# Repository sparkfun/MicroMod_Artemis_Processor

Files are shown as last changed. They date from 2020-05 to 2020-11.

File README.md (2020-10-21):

SparkFun MicroMod Artemis Processor Board
========================================

SparkFun MicroMod Artemis Processor Board

[*SparkFun MicroMod Artemis Processor Board (16401)*](https://www.sparkfun.com/products/16401)

Leveraging the ultra powerful Artemis Module, the SparkFun MicroMod Artemis Processor is the brain board of your dreams. Need Machine Learning capabilities? We gotcha. Need Bluetooth? We gotcha. Need I<sup>2</sup>C functionality to connect to all our amazing Qwiic boards? We totally gotcha.  

At the heart of SparkFun's Artemis module is Ambiq Micro's Apollo3 processor, whose ultra-efficient ARM Cortex-M4F processor is spec’d to run TensorFlow Lite using only 6uA/MHz. We've routed 2 I<sup>2</sup>C buses, 8 GPIO, dedicated digital, analog, and PWM pins, multiple SPI as well as QuadSPI, and Bluetooth to boot. You really can't go wrong with this processor. Grab one today, pick up a compatible carrier board, and get hacking! 

Repository Contents
-------------------

* **/Hardware** - Eagle design files (.brd, .sch)
* **/TestSketches** - Related software for the MicroMod Artemis Processor Board

Documentation
--------------
* **[Hookup Guide](https://learn.sparkfun.com/tutorials/micromod-artemis-processor-board-hookup-guide)** - Basic hookup guide for the MicroMod Artemis Processor Board.
* **[Getting Started with MicroMod](https://learn.sparkfun.com/tutorials/getting-started-with-micromod)** - A tutorial to help you get started with the MicroMod Ecosystem. 
* **[Designing with MicroMod](https://learn.sparkfun.com/tutorials/designing-with-micromod)** - A tutorial to walk you through the specs of the MicroMod processor and carrier board as well as the basics of incorporating the MicroMod form factor into your own PCB designs.

License Information
-------------------

This product is _**open source**_! 

Please review the LICENSE.md file for license information. 

If you have any questions or concerns on licensing, please contact technical support on our [SparkFun forums](https://forum.sparkfun.com/viewforum.php?f=152).

Distributed as-is; no warranty is given.

- Your friends at SparkFun.

_<COLLABORATION CREDIT>_

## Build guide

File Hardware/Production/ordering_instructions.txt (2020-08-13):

panel size, 194x70mm
PCB thickness, 0.8mm
number of layers, 4
soldermask color, Red
silkscreen color, White
oz copper, 1oz
finish, HASL lead free
stencils, none
pcs per panel, 16
min trace width, 0.1016mm / 0.0040in
min drill size, 0.2000mm / 0.0079in
filename to layer stackup 1/2/3/4: GTL, GL2, GL3, GBL

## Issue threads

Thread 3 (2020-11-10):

Battery voltage calculations with loaded voltage divider

adamgarbo, 2020-11-10:
Hi there,

I've been attempting to calculate the battery voltage using the Artemis Process and MicroMod Data Logging Carrier Board (MMDLCB).

From the schematics, we can observe that the 20 kΩ/10 kΩ voltage divider from the MMDLCB is loading the 100 kΩ/150 kΩ voltage divider on the Artemis. The circuit simplifies down to the following:

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

I've done the math to calculate the voltage across VR4, which seems to checkout, but the problem is the same calculations using the analog readings I'm getting on the Artemis don't appear to add up. I wrote the following code to test:

```
const float R1 = 20000.0;
const float R2 = 10000.0;
const float R3 = 100000.0;
const float R4 = 150000.0;
float R234 = 1.0 / ((1.0 / R2) + (1.0 / (R3 + R4)));

void setup() {

  Serial.begin(115200);
  while (!Serial);
  analogReadResolution(14);

  Serial.printf("R1: %.2f\n", R1);
  Serial.printf("R2: %.2f\n", R2);
  Serial.printf("R3: %.2f\n", R3);
  Serial.printf("R4: %.2f\n", R4);
  Serial.printf("R234: %.2f\n", R234);
}

void loop() {

  int VR4_ANALOG = analogRead(BATTVIN3);
  float VR4 = float(VR4_ANALOG) * 2.0 / 16384.0;
  float VR2 = VR4 * (R3 + R4) / R4;
  float VIN = VR2 * (R234 + R1) / R234;
  Serial.printf("VR4_ANALOG: %d VR4: %.2f VR2: %.2f VS: %.2f \n", VR4_ANALOG, VR4, VR2, VIN);
  delay(1000);
}
```

I'm wondering if perhaps I'm missing something regarding which ADC voltages are used. I've been operating under the assumption that the 2.0 V reference should be used.

Would be great to get some clarification on this (or for someone to double-check my math).

Cheers,
Adam

adamgarbo, 2020-11-10:
@PaulZC reminded me that we've encountered this issue before!

https://github.com/sparkfun/OpenLog_Artemis/issues/11#issuecomment-637340564

By the sounds of it, the higher resistance is worsening our accuracy and a correction factor will be needed to calculate the correct battery voltage measurement.

PaulZC, 2020-12-10:
Hi Adam (@adamgarbo ),
You've correctly spotted that the second divider will be loading the first and throwing the measurement off, but yes the 100k divider will limit how fast the ADC sample-and-hold capacitor can charge up leading to further scale errors.
In this case, I think you need a hybrid model that takes both effects into account.
All the best,
Paul

nseidle, 2020-12-10:
As I have learned recently with the [RTK Surveyor](https://www.sparkfun.com/products/17369), you may be better off with a fuel gauge IC such as the MAX1704x family (MAX17048 is what we use). These very low power devices are much better at correctly measuring a battery in a low-power situation.

adamgarbo, 2021-03-19:
Hi @PaulZC,

I'm revisiting this issue as I have a number of projects based on the Artemis Processor on the go and am hoping to find a way to make use of the Artemis' onboard battery voltage divider.

I read over your GitHub issue investigating using a voltage divider with the OpenLog Artemis. Would you be able to offer any insight on how to calculate a correction factor to use with the voltage dividers on the Artemis Processor and Data Logging Carrier Board? Will it be a matter of applying known voltages to the circuit and calculating backwards to properly scale the readings? This has really been making my brain hurt!

@nseidle is the plan to do away with the voltage divider entirely on the next hardware revision of the Artemis Processor?

Cheers,
Adam

PaulZC, 2021-03-19:
Hi @adamgarbo ,
Here's what I would do:
Apply a known, measured voltage. Step the voltage up in say 0.1V increments. Record the raw ADC codes from the analogRead. Throw the results into a spreadsheet and fit a y = ax + b line to them. You need to find the gain term (a) and there is probably an offset too (b) which may be negative.
I had to do the same thing on an ESP32 project recently.
It's a bit more tricky if you're calibrating the battery voltage circuit as you are then limited to say 3.6V up to whatever the maximum the voltage regulator can handle is. Usually around 6.0V. But it works.
Everything should be linear, you shouldn't have to introduce an x^2 term.
Cheers,
Paul

PaulZC, 2021-03-19:
Here's the spreadsheet from the ESP32 project.
Column A is the 'battery' voltage from a lab power supply.
Column C is the raw ADC reading.
The graph is raw ADC vs. voltage. It's linear.
Cell B6 is the voltage range (max - min).
Cell D6 is the ADC range (max - min).
Cell D8 is the calculated gain term: ADC range / voltage range.
Cell E8 is the offset term, entered manually and tweaked up and down until the values is column F look right - when compared to column C.
Column E is battery voltage minus offset.
Column F is (battery voltage - offset) * gain term.
Column H is the predicted voltages from the equation (ADC / CellD8) + CellE8 which, as I check, I compare visually to column A.
So, in this case, battery voltage = (raw ADC / 392) + 0.565.
Enjoy!

[ESP32_VIN.zip](https://github.com/sparkfun/MicroMod_Artemis_Processor/files/6169684/ESP32_VIN.zip)

adamgarbo, 2021-03-19:
Thanks, Paul!

It sounds like it's time to go dig up a power supply from the lab.

Am I correct in assuming the op-amp issues with the Artemis Processor shouldn't be a problem when characterizing the voltage measurements, since BATTVIN3 will only see at most 6.0 V / 3 = 2.0 V, which is within the limited 2.9 V range?

I see now why Nathan recommends the MAX17048 IC fuel gauge!

Cheers,
Adam

idea--list, 2021-10-10:
@adamgarbo
I think the best option to power Apollo3 chips is to use LiFePO batteries as the highest voltage this chip can tolerate is 3.63V.
LiFePOs are suit better for ultra low power applications than LiPOs, can tolerate cold wheather much better, have much longer lifecycles and cost way less per Wh, though their energy density is lower.
Now all the Sparkfun boards can be operated with LiPO batteries only as the SFE boards include power regulators that suit LiPOs and output constant 3V3 ...but exactly that is why reading the voltage divider built into the Apollo3 chips does not make any sense on SFE boards.

Instead i rely on a 2M and a 1M external resistor to have _**rough**_ estimate readings for LiPOs... as the voltage of LiFePOs hardly changes, dividers do not make much sense with that type of batteries.

IMHO the best option is what Nathan suggested.

adamgarbo, 2022-10-23:
Issue closed as unresolved.

Closed 2022-10-23.

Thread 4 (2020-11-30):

Incorrect analogRead() measurements

adamgarbo, 2020-11-30:
Howdy,

There currently appears to be an issue with obtaining correct analogRead() measurements with the Artemis Processor.

Plugging into the MicroMod Data Logging Carrier Board and running the Artemis example: `Example4_analogRead` reveals that when tied to GND, the analog measurement is correct (0). However, when 3.3 V is applied, the analog reading maxes out at ~15890/16384.

```
10:23:12.517 -> SparkFun Arduino Apollo3 Analog Read example
10:23:12.517 -> A0: 0	VCC/3: 8799 VCC: 3.22V	internalTemp: 26.85	vss: 0
10:23:12.620 -> A0: 0	VCC/3: 8799 VCC: 3.22V	internalTemp: 27.18	vss: 0
10:23:12.726 -> A0: 0	VCC/3: 8801 VCC: 3.22V	internalTemp: 27.54	vss: 0
10:23:12.799 -> A0: 0	VCC/3: 8806 VCC: 3.22V	internalTemp: 27.54	vss: 0
10:23:12.908 -> A0: 0	VCC/3: 8801 VCC: 3.22V	internalTemp: 27.32	vss: 0
10:23:13.010 -> A0: 0	VCC/3: 8801 VCC: 3.22V	internalTemp: 27.10	vss: 0
10:23:13.110 -> A0: 0	VCC/3: 8802 VCC: 3.22V	internalTemp: 27.21	vss: 0
10:23:13.213 -> A0: 0	VCC/3: 8801 VCC: 3.22V	internalTemp: 26.59	vss: 0
10:23:13.316 -> A0: 0	VCC/3: 8805 VCC: 3.22V	internalTemp: 27.10	vss: 0
10:23:13.417 -> A0: 0	VCC/3: 8803 VCC: 3.22V	internalTemp: 26.81	vss: 0
10:23:13.520 -> A0: 0	VCC/3: 8805 VCC: 3.22V	internalTemp: 27.21	vss: 0
10:23:13.626 -> A0: 0	VCC/3: 8801 VCC: 3.22V	internalTemp: 27.14	vss: 0
...
10:23:19.105 -> A0: 15889	VCC/3: 8808 VCC: 3.23V	internalTemp: 26.66	vss: 0
10:23:19.208 -> A0: 15882	VCC/3: 8801 VCC: 3.22V	internalTemp: 26.88	vss: 0
10:23:19.311 -> A0: 15891	VCC/3: 8799 VCC: 3.22V	internalTemp: 26.26	vss: 0
10:23:19.417 -> A0: 15890	VCC/3: 8808 VCC: 3.23V	internalTemp: 27.32	vss: 0
10:23:19.524 -> A0: 15894	VCC/3: 8808 VCC: 3.23V	internalTemp: 26.77	vss: 0
10:23:19.627 -> A0: 15890	VCC/3: 8800 VCC: 3.22V	internalTemp: 27.07	vss: 0
10:23:19.702 -> A0: 15882	VCC/3: 8801 VCC: 3.22V	internalTemp: 27.29	vss: 0
10:23:19.803 -> A0: 15885	VCC/3: 8806 VCC: 3.22V	internalTemp: 26.77	vss: 0
10:23:19.909 -> A0: 15880	VCC/3: 8802 VCC: 3.22V	internalTemp: 27.36	vss: 0
10:23:20.013 -> A0: 15883	VCC/3: 8799 VCC: 3.22V	internalTemp: 27.36	vss: 0
10:23:20.117 -> A0: 15885	VCC/3: 8802 VCC: 3.22V	internalTemp: 26.85	vss: 0
10:23:20.224 -> A0: 15892	VCC/3: 8802 VCC: 3.22V	internalTemp: 27.03	vss: 0
10:23:20.329 -> A0: 15878	VCC/3: 8802 VCC: 3.22V	internalTemp: 27.14	vss: 0
```

Similarly, when running the `ADC.ino` example included in the Artemis Processor repo, applying 3.3 V to both A0 and A1 reveals incorrect voltage measurements.

```
10:28:59.335 -> A0 voltage: 3.197	A1 voltage: 3.211	battvin: 6188	Batt voltage: 1.246
10:28:59.369 -> A0 voltage: 3.197	A1 voltage: 3.209	battvin: 6195	Batt voltage: 1.248
10:28:59.438 -> A0 voltage: 3.199	A1 voltage: 3.205	battvin: 6191	Batt voltage: 1.247
10:28:59.471 -> A0 voltage: 3.199	A1 voltage: 3.205	battvin: 6189	Batt voltage: 1.247
10:28:59.538 -> A0 voltage: 3.198	A1 voltage: 3.210	battvin: 6188	Batt voltage: 1.246
10:28:59.574 -> A0 voltage: 3.200	A1 voltage: 3.207	battvin: 6186	Batt voltage: 1.246
10:28:59.642 -> A0 voltage: 3.199	A1 voltage: 3.211	battvin: 6198	Batt voltage: 1.248
10:28:59.711 -> A0 voltage: 3.199	A1 voltage: 3.210	battvin: 6191	Batt voltage: 1.247
10:28:59.746 -> A0 voltage: 3.199	A1 voltage: 3.206	battvin: 6198	Batt voltage: 1.248
10:28:59.781 -> A0 voltage: 3.199	A1 voltage: 3.207	battvin: 6184	Batt voltage: 1.246
10:28:59.852 -> A0 voltage: 3.199	A1 voltage: 3.206	battvin: 6191	Batt voltage: 1.247
10:28:59.885 -> A0 voltage: 3.198	A1 voltage: 3.210	battvin: 6183	Batt voltage: 1.245
10:28:59.952 -> A0 voltage: 3.198	A1 voltage: 3.205	battvin: 6184	Batt voltage: 1.246
10:28:59.987 -> A0 voltage: 3.199	A1 voltage: 3.206	battvin: 6197	Batt voltage: 1.248
```

I suspect this issue is linked to the incorrect battery measurements in #3 and ultimately connected to the resistor dividers on the TSV524 op-amp channels, but I must admit that I'm not overly familiar with op-amps. Will users need a correction factor to apply to all analog readings?

Cheers,
Adam

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

PaulZC, 2020-12-10:
Hi Adam (@adamgarbo ),
In this case, I suspect it is more to do with the op-amp not being able to swing all the way to the +ve rail.
With 3.3V on (e.g.) ADC0, you are asking pin 15 to swing to 3.3V and it probably can't do it...
There's no easy 'scale' fix for this. Once ADC0 drops below about 3.2V, pin 15 will faithfully follow the input 1:1.
The only ways to fix it would be to find a true rail-to-rail op-amp, or increase VCC for the op-amp by around 0.2V.
All the best,
Paul

adamgarbo, 2020-12-10:
Thanks for the input @PaulZC!

A tricky situation! Any thoughts @nseidle? The TSV524 op-amp also looks to be responsible for ~150 uA of quiescent draw that can't be disabled (to my knowledge), so it'd be great to address both issues in one fell swoop.

Cheers,
Adam

nseidle, 2020-12-10:
The op-amp scaling is used to get the 2V max of the Apollo3 near the 3.3V ADC range of MicroMod. It's not perfect and as Paul points out is prone to clipping.

And just to be the bearer of bad news, the op-amp is sitting behind the RTC diode which means it's max swing is about 2.9V. A good solution would be to move the TSV524 to be powered from the 'raw' side of the D7 diode. This should solve both your problems (TVS won't draw current when in sleep mode) and increase the overhead voltage a bit, but without a rail-to-rail opamp (as Paul points out) we'll be limited at the high end.

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

adamgarbo, 2020-12-15:
Thanks @nseidle & @PaulZC,

So to clarify for users, ADC measurements are currently not working on this version of Artemis Processor?

Will this require a hardware revision to fix?

Cheers,
Adam

PaulZC, 2020-12-15:
Hi @adamgarbo,

The ADC is working just fine. The only issue is that you do not quite have access to the full 3.3V range. Voltages up to 2.9V should be perfectly OK.

Best wishes,

Paul

adamgarbo, 2020-12-18:
Thanks @PaulZC for the clarification. I could have better phrased the question as "not fully working as intended".

Analog measurements have always been tricky with the Artemis. The argument could be made for end-users who rely on having a full range for ADC measurements that there's ultimately little difference between the Artemis' inherent 0-2 V range vs. the op-amp's 0-2.9 V range. It's usually an all or nothing situation.

I'm curious to see what the future holds for the Artemis Processor. While it'd be great to have scaling working across the entire range, it may be easier to simply remove the op-amp circuity and the onboard battery voltage divider, which users are currently unable to make use of.

Happy to assist in any way I can!

Cheers,
Adam

adamgarbo, 2021-01-08:
Hi guys,

To confirm my earlier suspicions, I measured the deep sleep current draw of a brand new Artemis Processor this morning (R.I.P. the previous Artemis I accidentally blew up when first attempting this) and it was approximately 144.4 uA.

With the current placement of the TSV524, is there any way to actually decrease the current draw, save for physically removing the op-amp?

Cheers,
Adam

adamgarbo, 2022-10-23:
Issue closed as unresolved.

Closed 2022-10-23.

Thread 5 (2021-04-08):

To fix: Op-amp circuitry

adamgarbo, 2021-04-08:
Hi @nseidle,

Throwing this issue up just as a reminder for the next hardware revision of the MicroMod Artemis Processor (a long way down the road).

Currently, the op-amp circuitry on the Artemis Processor is causing a number of major issues, including:
* Limited ADC measurement range of 0-2.9 V
* 50-100x greater quiescent current consumption (150 - 200 uA vs 2.5 uA)
* Loaded voltage divider preventing accurate battery voltage measurements

Enabling the Artemis to make analog measurements across a 0-3.3 V range is a great feature, and I think it just needs a little more attention to ensure that it works correctly.

Cheers,
Adam

adamgarbo, 2022-10-23:
Issue closed as unresolved.

Closed 2022-10-23.

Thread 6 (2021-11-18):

RTC battery backup does not keep charge

adamgarbo, 2021-11-18:
Hi there,

I realized I'd forgotten to create a GitHub issue about a problem I encountered with the RTC battery backup and Artemis Processor.

I discovered that when using the Artemis Processor and MicroMod Data Logging Carrier Board (MMDLCB), the RTC will not retain its time when the power is removed. To test this, I charged the battery for 24 hours and then unplugged power to the MMDLCB for two minutes. Even after this short time, the battery-backup seems to discharge to the point where it's no long able to maintain the RTC.

I had made a forum post about this and it was acknowledged as a design issue:
https://forum.sparkfun.com/viewtopic.php?f=181&t=55312&p=224100&hilit=backup+drain#p224023

I am curious if it's the same issue as the RP2040 Processor, which had its RTC_3V pin mistakenly tied to 3.3V: https://github.com/sparkfun/MicroMod_Processor-RP2040/issues/1#issuecomment-799603389

```
08:31:30.651 -> SparkFun RTC Example
08:31:30.651 -> It is now 12:31:31.40 03/15/21 Day of week: 1 = Monday
08:31:31.657 -> It is now 12:31:32.40 03/15/21 Day of week: 1 = Monday
08:31:32.673 -> It is now 12:31:33.41 03/15/21 Day of week: 1 = Monday
08:31:33.665 -> It is now 12:31:34.41 03/15/21 Day of week: 1 = Monday
08:31:34.678 -> It is now 12:31:35.42 03/15/21 Day of week: 1 = Monday
08:31:35.683 -> It is now 12:31:36.42 03/15/21 Day of week: 1 = Monday
08:31:36.690 -> It is now 12:31:37.43 03/15/21 Day of week: 1 = Monday
08:31:37.693 -> It is now 12:31:38.43 03/15/21 Day of week: 1 = Monday
08:31:38.690 -> It is now 12:31:39.44 03/15/21 Day of week: 1 = Monday
08:31:39.692 -> It is now 12:31:40.44 03/15/21 Day of week: 1 = Monday
08:31:40.716 -> It is now 12:31:41.45 03/15/21 Day of week: 1 = Monday
08:31:41.722 -> It is now 12:31:42.45 03/15/21 Day of week: 1 = Monday
08:31:42.718 -> It is now 12:31:43.45 03/15/21 Day of week: 1 = Monday
08:31:43.705 -> It is now 12:31:44.46 03/15/21 Day of week: 1 = Monday
08:31:44.733 -> It is now 12:31:45.46 03/15/21 Day of week: 1 = Monday
08:31:45.725 -> It is now 12:31:46.47 03/15/21 Day of week: 1 = Monday
08:31:46.718 -> It is now 12:31:47.47 03/15/21 Day of week: 1 = Monday
08:31:47.722 -> It is now 12:31:48.48 03/15/21 Day of week: 1 = Monday
08:31:48.738 -> It is now 12:31:49.48 03/15/21 Day of week: 1 = Monday
08:31:49.748 -> It is now 12:31:50.49 03/15/21 Day of week: 1 = Monday
08:31:50.763 -> It is now 12:31:51.49 03/15/21 Day of week: 1 = Monday
08:31:51.773 -> It is now 12:31:52.50 03/15/21 Day of week: 1 = Monday
08:31:52.759 -> It is now 12:31:53.50 03/15/21 Day of week: 1 = Monday
08:31:53.760 -> It is now 12:31:54.50 03/15/21 Day of week: 1 = Monday
08:31:54.773 -> It is now 12:31:55.51 03/15/21 Day of week: 1 = Monday
08:31:55.781 -> It is now 12:31:56.51 03/15/21 Day of week: 1 = Monday
08:31:56.791 -> It is now 12:31:57.52 03/15/21 Day of week: 1 = Monday
08:31:57.777 -> It is now 12:31:58.52 03/15/21 Day of week: 1 = Monday
08:31:58.777 -> It is now 12:31:59.53 03/15/21 Day of week: 1 = Monday
08:31:59.784 -> It is now 12:32:00.53 03/15/21 Day of week: 1 = Monday <- Unplugged power
08:34:01.698 -> SparkFun RTC Example <- Plugged in power
08:34:01.976 -> It is now 0:00:01.69 01/01/00 Day of week: 0 = Sunday
08:34:02.970 -> It is now 0:00:02.68 01/01/00 Day of week: 0 = Sunday
08:34:03.963 -> It is now 0:00:03.68 01/01/00 Day of week: 0 = Sunday
08:34:04.959 -> It is now 0:00:04.69 01/01/00 Day of week: 0 = Sunday
08:34:05.994 -> It is now 0:00:05.69 01/01/00 Day of week: 0 = Sunday
08:34:06.970 -> It is now 0:00:06.69 01/01/00 Day of week: 0 = Sunday
08:34:07.985 -> It is now 0:00:07.70 01/01/00 Day of week: 0 = Sunday
08:34:09.001 -> It is now 0:00:08.70 01/01/00 Day of week: 0 = Sunday
08:34:09.990 -> It is now 0:00:09.70 01/01/00 Day of week: 0 = Sunday
08:34:11.003 -> It is now 0:00:10.71 01/01/00 Day of week: 0 = Sunday
08:34:12.000 -> It is now 0:00:11.71 01/01/00 Day of week: 0 = Sunday
08:34:12.997 -> It is now 0:00:12.71 01/01/00 Day of week: 0 = Sunday
08:34:14.007 -> It is now 0:00:13.72 01/01/00 Day of week: 0 = Sunday
08:34:14.990 -> It is now 0:00:14.72 01/01/00 Day of week: 0 = Sunday
08:34:16.009 -> It is now 0:00:15.72 01/01/00 Day of week: 0 = Sunday
08:34:17.017 -> It is now 0:00:16.72 01/01/00 Day of week: 0 = Sunday
08:34:18.016 -> It is now 0:00:17.73 01/01/00 Day of week: 0 = Sunday
08:34:19.009 -> It is now 0:00:18.73 01/01/00 Day of week: 0 = Sunday
08:34:20.005 -> It is now 0:00:19.73 01/01/00 Day of week: 0 = Sunday
08:34:21.033 -> It is now 0:00:20.74 01/01/00 Day of week: 0 = Sunday
08:34:22.029 -> It is now 0:00:21.74 01/01/00 Day of week: 0 = Sunday
08:34:23.039 -> It is now 0:00:22.74 01/01/00 Day of week: 0 = Sunday
08:34:24.018 -> It is now 0:00:23.75 01/01/00 Day of week: 0 = Sunday
08:34:25.032 -> It is now 0:00:24.75 01/01/00 Day of week: 0 = Sunday
08:34:26.052 -> It is now 0:00:25.75 01/01/00 Day of week: 0 = Sunday
08:34:27.052 -> It is now 0:00:26.75 01/01/00 Day of week: 0 = Sunday
08:34:28.042 -> It is now 0:00:27.76 01/01/00 Day of week: 0 = Sunday
08:34:29.049 -> It is now 0:00:28.76 01/01/00 Day of week: 0 = Sunday
08:34:30.039 -> It is now 0:00:29.76 01/01/00 Day of week: 0 = Sunday
08:34:31.059 -> It is now 0:00:30.77 01/01/00 Day of week: 0 = Sunday
```

Cheers,
Adam

adamgarbo, 2021-11-18:
I forgot to mention that I'm not entirely sure if this is an issue with the Artemis Processor or battery backup circuitry on the MicroMod Data Logging Carrier board.

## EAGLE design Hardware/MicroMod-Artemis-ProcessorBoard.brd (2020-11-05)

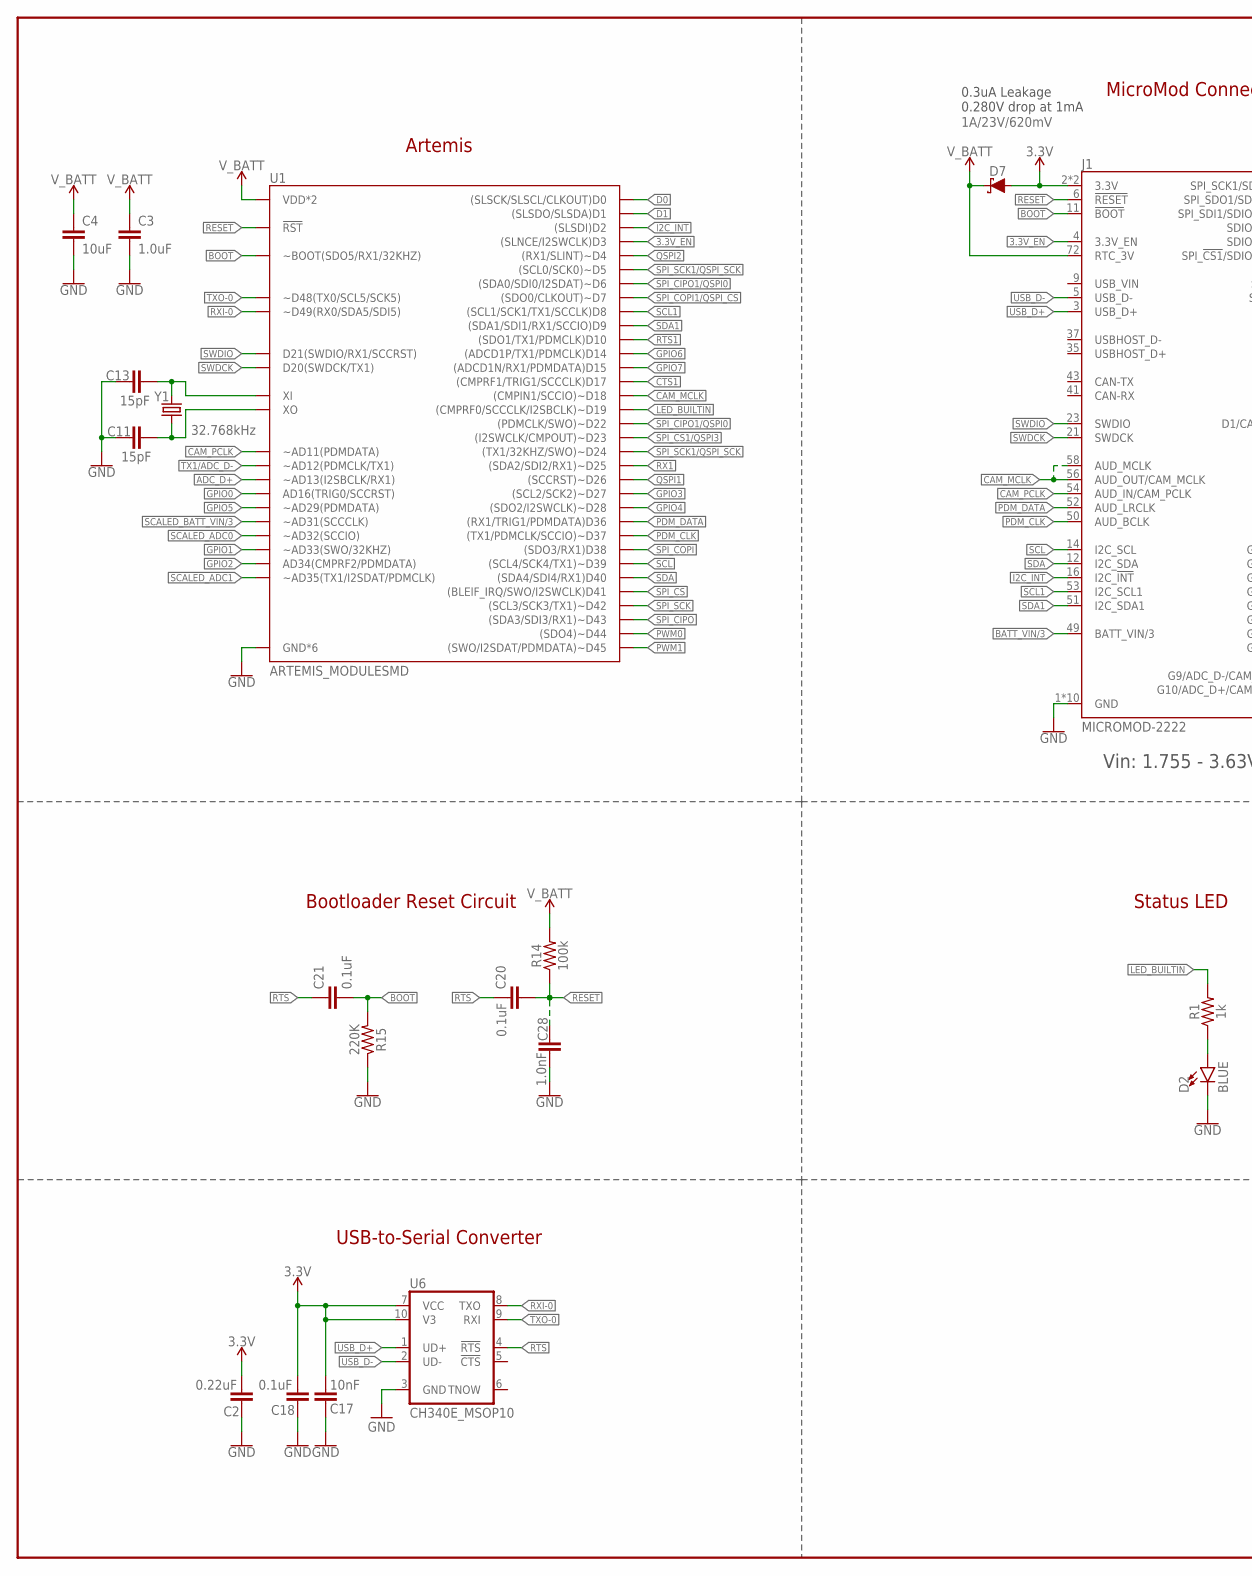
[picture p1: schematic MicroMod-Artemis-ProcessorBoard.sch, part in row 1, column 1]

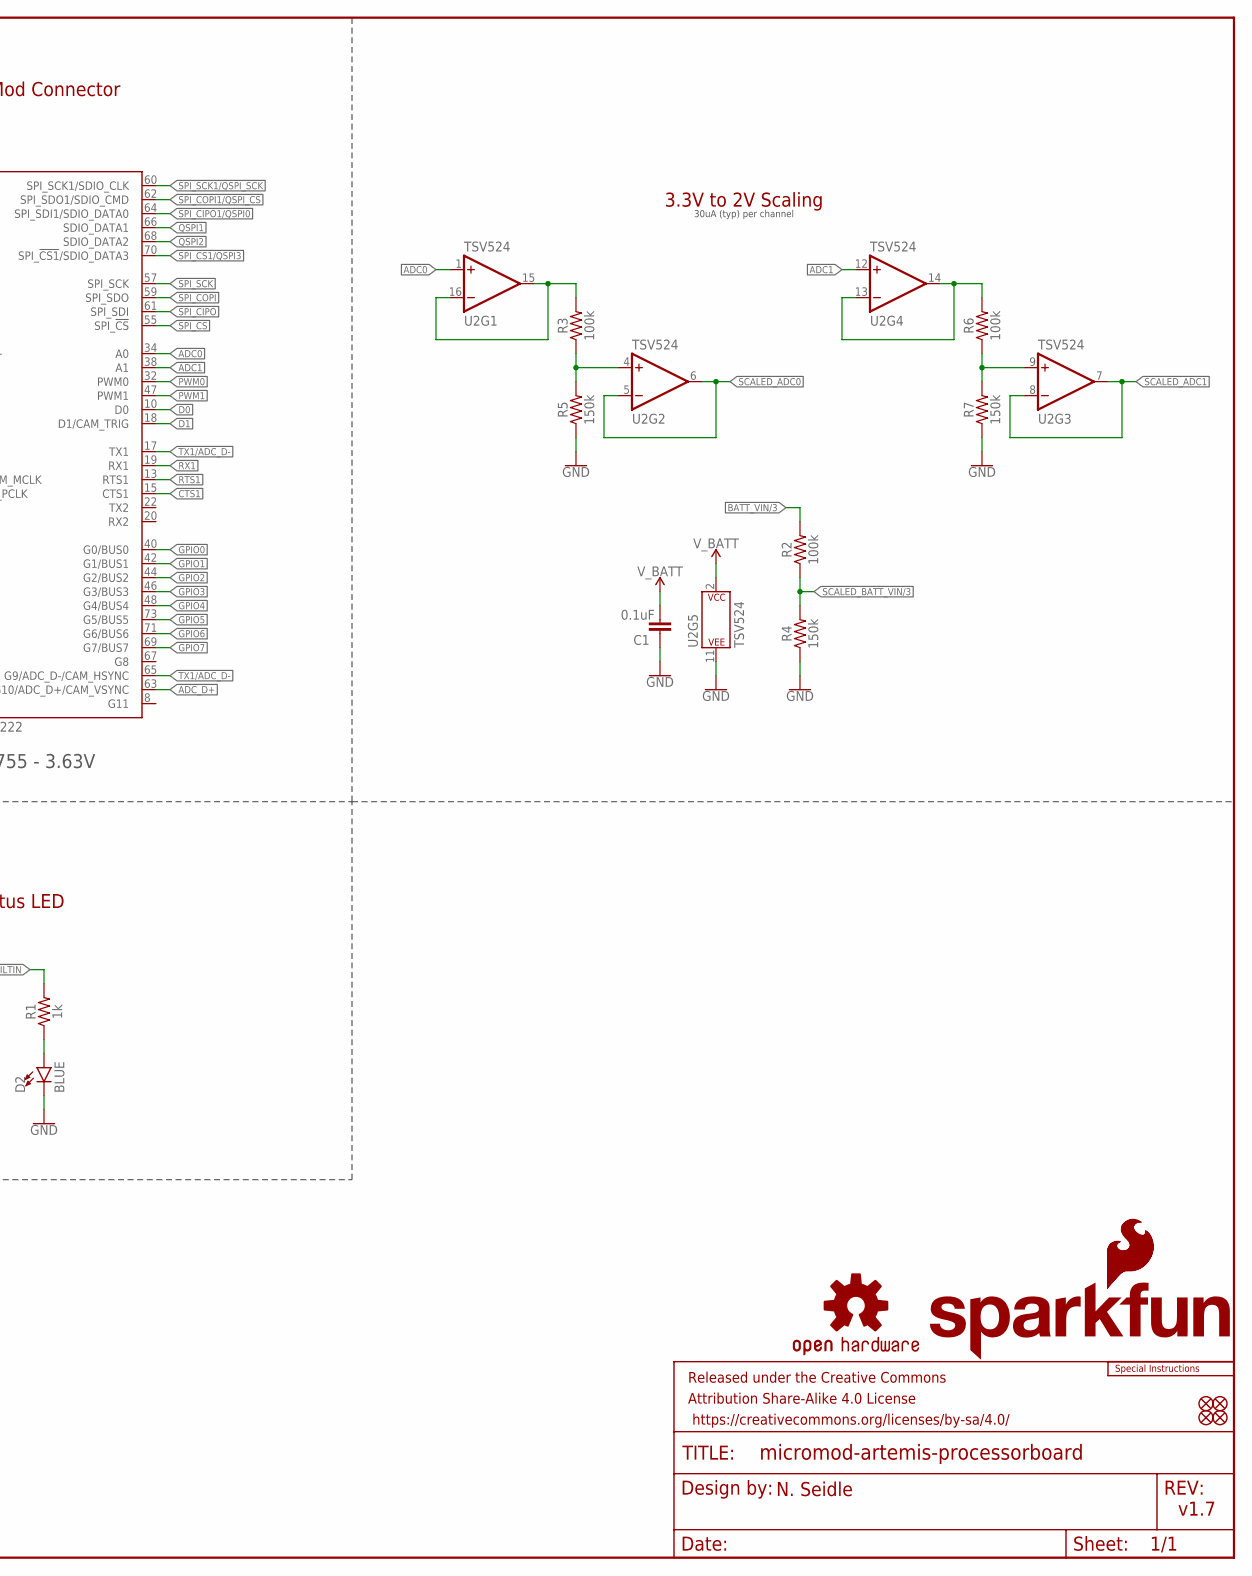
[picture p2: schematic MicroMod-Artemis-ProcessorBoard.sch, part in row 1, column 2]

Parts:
C1, C18, C20, C21: 0.1uF; 0402-TIGHT
C2: 0.22uF; 0402-TIGHT
C3: 1.0uF; 0402-TIGHT
C4: 10uF; 0603
C11, C13: 15pF; 0402-TIGHT
C17: 10nF; 0402-TIGHT
C28: 1.0nF; 0402-TIGHT
D2: BLUE; LED-0603
D7: 1A/23V/620mV; SOD-323
FD1, FD2, FD3, FD4: FIDUCIALUFIDUCIAL; FIDUCIAL-MICRO
FRAME1: FRAME-LEDGER; CREATIVE_COMMONS
J1: MICROMOD-2222; M.2-CARD-E-22
LOGO1: SFE_LOGO_NAME_FLAME.1_INCH; SFE_LOGO_NAME_FLAME_.1
LOGO2: SFE_LOGO_FLAME.1_INCH; SFE_LOGO_FLAME_.1
LOGO3: OSHW-LOGOMINI; OSHW-LOGO-MINI
LOGO4: SPECIAL_INSTRUCTIONS-ORDERING; ORDERING_INSTRUCTIONS
R1: 1k; 0402-TIGHT
R2, R3, R6, R14: 100k; 0402-TIGHT
R4, R5, R7: 150k; 0402-TIGHT
R15: 220K; 0402-TIGHT
U1: ARTEMIS_MODULESMD; ARTEMIS_FP
U2: TSV524; QFN-16
U6: CH340E_MSOP10; MSOP10
Y1: 32.768kHz; CRYSTAL-SMD-3.2X1.5MM

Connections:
3.3V: C2.1, C17.1, C18.1, D7.A, J1.2 (3.3V), J1.74 (3.3V), U6.7 (VCC), U6.10 (V3)
3.3V_EN: J1.4 (3.3V_EN), U1.D3 ((SLNCE/I2SWCLK)D3)
!RESET!: C20.2, C28.1, J1.6 (!RESET!), R14.1, U1.~RST (!RST)
!RTS: C20.1, C21.1, U6.4 (!RTS)
ADC0: J1.34 (A0), U2.1 (+IN)
ADC0_BUFF1: R3.2, U2.15 (OUT), U2.16 (-IN)
ADC0_BUFF2: R3.1, R5.2, U2.4 (+IN)
ADC1: J1.38 (A1), U2.12 (+IN)
ADC1_BUFF2: R6.1, R7.2, U2.9 (+IN)
ADC_BUFF1: R6.2, U2.13 (-IN), U2.14 (OUT)
ADC_D+: J1.63 (G10/ADC_D+/CAM_VSYNC), U1.~AD13 (~AD13(I2SBCLK/RX1))
BATT_VIN/3: J1.49 (BATT_VIN/3), R2.2
BOOT: C21.2, J1.11 (!BOOT!), R15.2, U1.BOOT (~BOOT(SDO5/RX1/32KHZ))
CAM_MCLK: J1.56 (AUD_OUT/CAM_MCLK), J1.58 (AUD_MCLK), U1.~D18 ((CMPIN1/SCCIO)~D18)
CAM_PCLK: J1.54 (AUD_IN/CAM_PCLK), U1.~AD11 (~AD11(PDMDATA))
CTS1: J1.15 (CTS1), U1.D17 ((CMPRF1/TRIG1/SCCCLK)D17)
D0: J1.10 (D0), U1.D0 ((SLSCK/SLSCL/CLKOUT)D0)
D1: J1.18 (D1/CAM_TRIG), U1.D1 ((SLSDO/SLSDA)D1)
GND: C1.2, C2.2, C3.2, C4.2, C11.1, C13.1, C17.2, C18.2, C28.2, D2.C, J1.1 (GND), J1.7 (GND), J1.33 (GND), J1.36 (GND), J1.39 (GND), J1.45 (GND), J1.75 (GND), J1.GND1 (GND), J1.GND2 (GND), J1.GND3 (GND), R4.1, R5.1, R7.1, R15.1, U1.GND@1 (GND*6), U1.GND@22 (GND*6), U1.GND@38 (GND*6), U1.GND@39 (GND*6), U1.GND@47 (GND*6), U1.GND@59 (GND*6), U2.11 (V-), U6.3 (GND)
GPIO0: J1.40 (G0/BUS0), U1.AD16 (AD16(TRIG0/SCCRST))
GPIO1: J1.42 (G1/BUS1), U1.~AD33/SWO (~AD33(SWO/32KHZ))
GPIO2: J1.44 (G2/BUS2), U1.AD34 (AD34(CMPRF2/PDMDATA))
GPIO3: J1.46 (G3/BUS3), U1.~D27 ((SCL2/SCK2)~D27)
GPIO4: J1.48 (G4/BUS4), U1.~D28 ((SDO2/I2SWCLK)~D28)
GPIO5: J1.73 (G5/BUS5), U1.~AD29 (~AD29(PDMDATA))
GPIO6: J1.71 (G6/BUS6), U1.D14 ((ADCD1P/TX1/PDMCLK)D14)
GPIO7: J1.69 (G7/BUS7), U1.D15 ((ADCD1N/RX1/PDMDATA)D15)
I2C_!INT!: J1.16 (I2C_!INT!), U1.D2 ((SLSDI)D2)
LED_BUILTIN: R1.2, U1.~D19 ((CMPRF0/SCCCLK/I2SBCLK)~D19)
unnamed: D2.A, R1.1
unnamed: C13.2, U1.XI, Y1.P$1 (1)
unnamed: C11.2, U1.XO, Y1.P$2 (2)
PDM_CLK: J1.50 (AUD_BCLK), U1.~D37 ((TX1/PDMCLK/SCCIO)~D37)
PDM_DATA: J1.52 (AUD_LRCLK), U1.D36 ((RX1/TRIG1/PDMDATA)D36)
PWM0: J1.32 (PWM0), U1.~D44 ((SDO4)~D44)
PWM1: J1.47 (PWM1), U1.~D45 ((SWO/I2SDAT/PDMDATA)~D45)
QSPI1: J1.66 (SDIO_DATA1), U1.~D26 ((SCCRST)~D26)
QSPI2: J1.68 (SDIO_DATA2), U1.~D4 ((RX1/SLINT)~D4)
RTS1: J1.13 (RTS1), U1.D10 ((SDO1/TX1/PDMCLK)D10)
RX1: J1.19 (RX1), U1.~D25 ((SDA2/SDI2/RX1)~D25)
RXI-0: U1.RXI-0 (~D49(RX0/SDA5/SDI5)), U6.8 (TXO)
SCALED_ADC0: U1.~AD32 (~AD32(SCCIO)), U2.5 (-IN), U2.6 (OUT)
SCALED_ADC1: U1.~AD35 (~AD35(TX1/I2SDAT/PDMCLK)), U2.7 (OUT), U2.8 (-IN)
SCALED_BATT_VIN/3: R2.1, R4.2, U1.~AD31 (~AD31(SCCCLK))
SCL: J1.14 (I2C_SCL), U1.~D39 ((SCL4/SCK4/TX1)~D39)
SCL1: J1.53 (I2C_SCL1), U1.D8 ((SCL1/SCK1/TX1/SCCLK)D8)
SDA: J1.12 (I2C_SDA), U1.D40 ((SDA4/SDI4/RX1)D40)
SDA1: J1.51 (I2C_SDA1), U1.D9 ((SDA1/SDI1/RX1/SCCIO)D9)
SPI_!CS1!/QSPI3: J1.70 (SPI_!CS1!/SDIO_DATA3), U1.~D23 ((I2SWCLK/CMPOUT)~D23)
SPI_!CS!: J1.55 (SPI_!CS!), U1.D41 ((BLEIF_IRQ/SWO/I2SWCLK)D41)
SPI_CIPO: J1.61 (SPI_SDI), U1.~D43 ((SDA3/SDI3/RX1)~D43)
SPI_CIPO1/QSPI0: J1.64 (SPI_SDI1/SDIO_DATA0), U1.~D6 ((SDA0/SDI0/I2SDAT)~D6), U1.~D22 ((PDMCLK/SWO)~D22)
SPI_COPI: J1.59 (SPI_SDO), U1.D38 ((SDO3/RX1)D38)
SPI_COPI1/QSPI_!CS!: J1.62 (SPI_SDO1/SDIO_CMD), U1.D7 ((SDO0/CLKOUT)~D7)
SPI_SCK: J1.57 (SPI_SCK), U1.~D42 ((SCL3/SCK3/TX1)~D42)
SPI_SCK1/QSPI_SCK: J1.60 (SPI_SCK1/SDIO_CLK), U1.~D5 ((SCL0/SCK0)~D5), U1.~D24 ((TX1/32KHZ/SWO)~D24)
SWDCK: J1.21 (SWDCK), U1.SWDCK (D20(SWDCK/TX1))
SWDIO: J1.23 (SWDIO), U1.SWDIO (D21(SWDIO/RX1/SCCRST))
TX1/ADC_D-: J1.17 (TX1), J1.65 (G9/ADC_D-/CAM_HSYNC), U1.~AD12 (~AD12(PDMCLK/TX1))
TXO-0: U1.TXO-0 (~D48(TX0/SCL5/SCK5)), U6.9 (RXI)
USB_D+: J1.3 (USB_D+), U6.1 (UD+)
USB_D-: J1.5 (USB_D-), U6.2 (UD-)
V_BATT: C1.1, C3.1, C4.1, D7.C, J1.72 (RTC_3V), R14.2, U1.VDD@36 (VDD*2), U1.VDD@37 (VDD*2), U2.2 (V+)

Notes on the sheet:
USB-to-Serial Converter
Bootloader Reset Circuit
MicroMod Connector
3.3V to 2V Scaling
v1.7
N. Seidle
Artemis
Status LED
Vin: 1.755 - 3.63V
0.3uA Leakage 0.280V drop at 1mA
30uA (typ) per channel

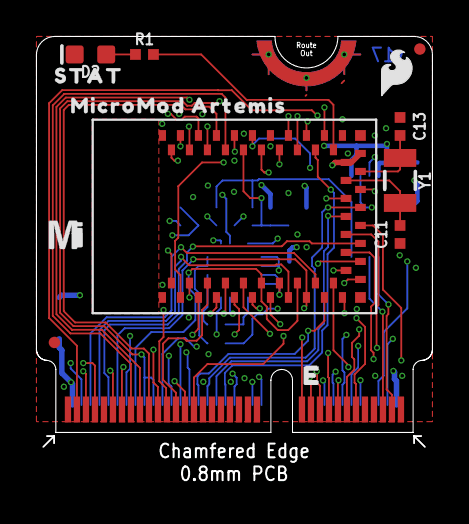
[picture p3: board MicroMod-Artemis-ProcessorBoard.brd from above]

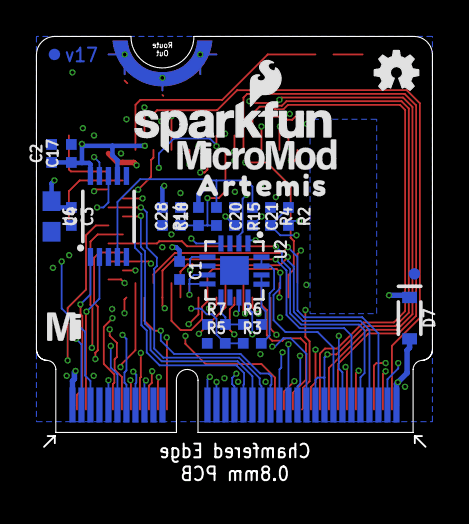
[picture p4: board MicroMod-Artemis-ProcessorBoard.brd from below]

Board: 4 copper layers, 22.0 x 22.8 mm, 42 parts (27 on the bottom side), 63 nets.

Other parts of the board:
U$1, U$7: MICROMOD_MI_LOGO_.35
U$5: MICROMOD_LOGO_.35
U$8: MICROMOD_ARTEMIS0
U$9: ARTEMIS0
U$11: STAT0

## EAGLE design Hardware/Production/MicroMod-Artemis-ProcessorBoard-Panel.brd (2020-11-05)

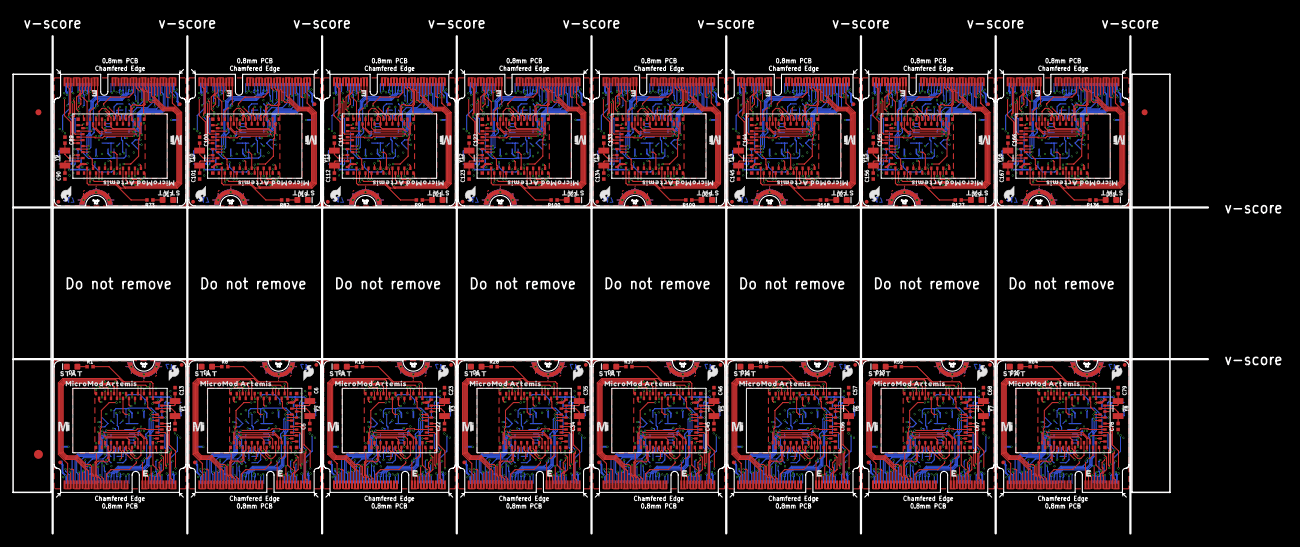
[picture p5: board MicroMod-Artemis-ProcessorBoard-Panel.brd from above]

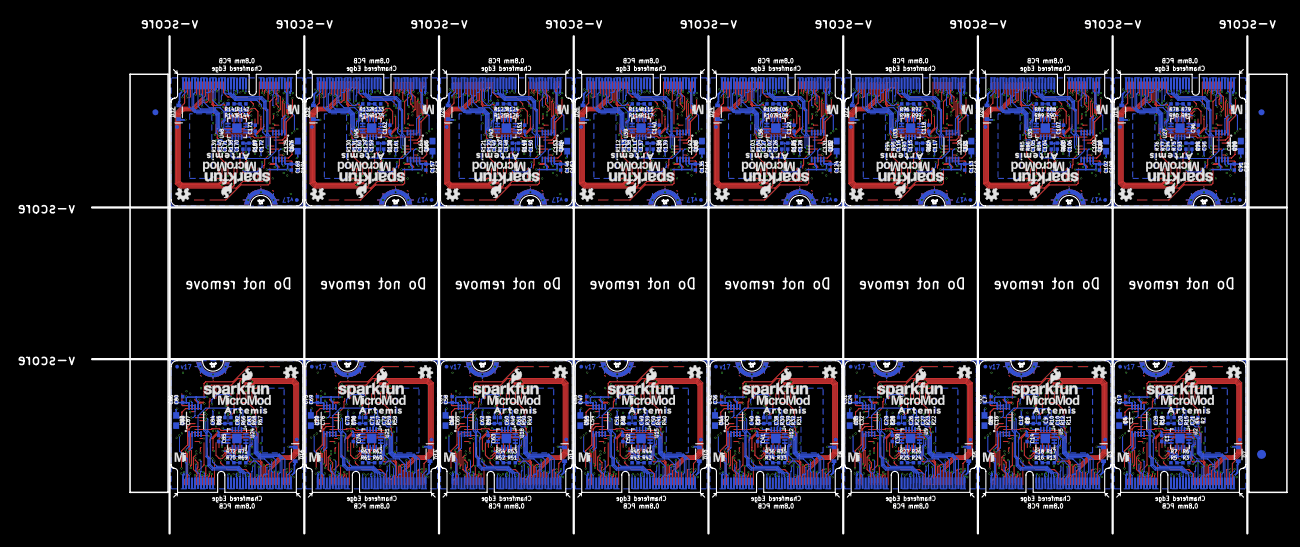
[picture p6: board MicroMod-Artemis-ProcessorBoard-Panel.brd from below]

Board: 4 copper layers, 199.6 x 83.1 mm, 646 parts (435 on the bottom side), 1008 nets.

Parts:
C1, C8, C9, C10, C14, C18, C20, C21, C25, C26, C27, C30, C37, C38, C39, C41, C48, C49, C50, C52, C59, C60, C61, C63, C70, C71, C72, C74, C81, C82, C83, C85, C92, C93, C94, C96, C103, C104, C105, C107, C114, C115, C116, C118, C125, C126, C127, C129, C136, C137, C138, C140, C147, C148, C149, C151, C158, C159, C160, C162, C169, C170, C171, C173: 0.1uF; 0402-TIGHT
C2, C15, C31, C42, C53, C64, C75, C86, C97, C108, C119, C130, C141, C152, C163, C174: 0.22uF; 0402-TIGHT
C3, C16, C32, C43, C54, C65, C76, C87, C98, C109, C120, C131, C142, C153, C164, C175: 1.0uF; 0402-TIGHT
C4, C19, C33, C44, C55, C66, C77, C88, C99, C110, C121, C132, C143, C154, C165, C176: 10uF; 0603
C5, C6, C11, C13, C22, C23, C34, C35, C45, C46, C56, C57, C67, C68, C78, C79, C89, C90, C100, C101, C111, C112, C122, C123, C133, C134, C144, C145, C155, C156, C166, C167: 15pF; 0402-TIGHT
C7, C17, C24, C36, C47, C58, C69, C80, C91, C102, C113, C124, C135, C146, C157, C168: 10nF; 0402-TIGHT
C12, C28, C29, C40, C51, C62, C73, C84, C95, C106, C117, C128, C139, C150, C161, C172: 1.0nF; 0402-TIGHT
D1, D2, D4, D6, D9, D11, D13, D15, D17, D19, D21, D23, D25, D27, D29, D31: BLUE; LED-0603
D3, D5, D7, D8, D10, D12, D14, D16, D18, D20, D22, D24, D26, D28, D30, D32: 1A/23V/620mV; SOD-323
E$1, E$2, E$3, E$4: FIDUCIAL-1X2
E$5, E$6: FIDUCIAL-1.5X3
FD1, FD2, FD3, FD4, FD5, FD6, FD7, FD8, FD9, FD10, FD11, FD12, FD13, FD14, FD15, FD16, FD17, FD18, FD19, FD20, FD21, FD22, FD23, FD24, FD25, FD26, FD27, FD28, FD29, FD30, FD31, FD32, FD33, FD34, FD35, FD36, FD37, FD38, FD39, FD40, FD41, FD42, FD43, FD44, FD45, FD46, FD47, FD48, FD49, FD50, FD51, FD52, FD53, FD54, FD55, FD56, FD57, FD58, FD59, FD60, FD61, FD62, FD63, FD64: FIDUCIALUFIDUCIAL; FIDUCIAL-MICRO
J1, J2, J3, J4, J5, J6, J7, J8, J9, J10, J11, J12, J13, J14, J15, J16: MICROMOD-2222; M.2-CARD-E-22
LOGO1, LOGO5, LOGO8, LOGO11, LOGO14, LOGO17, LOGO20, LOGO23, LOGO26, LOGO29, LOGO32, LOGO35, LOGO38, LOGO41, LOGO44, LOGO47: SFE_LOGO_NAME_FLAME.1_INCH; SFE_LOGO_NAME_FLAME_.1
LOGO2, LOGO6, LOGO9, LOGO12, LOGO15, LOGO18, LOGO21, LOGO24, LOGO27, LOGO30, LOGO33, LOGO36, LOGO39, LOGO42, LOGO45, LOGO48: SFE_LOGO_FLAME.1_INCH; SFE_LOGO_FLAME_.1
LOGO3, LOGO4, LOGO7, LOGO10, LOGO13, LOGO16, LOGO19, LOGO22, LOGO25, LOGO28, LOGO31, LOGO34, LOGO37, LOGO40, LOGO43, LOGO46: OSHW-LOGOMINI; OSHW-LOGO-MINI
R1, R8, R19, R28, R37, R46, R55, R64, R73, R82, R91, R100, R109, R118, R127, R136: 1k; 0402-TIGHT
R2, R3, R6, R9, R11, R13, R14, R17, R20, R22, R24, R26, R29, R31, R33, R35, R38, R40, R42, R44, R47, R49, R51, R53, R56, R58, R60, R62, R65, R67, R69, R71, R74, R76, R78, R80, R83, R85, R87, R89, R92, R94, R96, R98, R101, R103, R105, R107, R110, R112, R114, R116, R119, R121, R123, R125, R128, R130, R132, R134, R137, R139, R141, R143: 100k; 0402-TIGHT
R4, R5, R7, R12, R16, R18, R23, R25, R27, R32, R34, R36, R41, R43, R45, R50, R52, R54, R59, R61, R63, R68, R70, R72, R77, R79, R81, R86, R88, R90, R95, R97, R99, R104, R106, R108, R113, R115, R117, R122, R124, R126, R131, R133, R135, R140, R142, R144: 150k; 0402-TIGHT
R10, R15, R21, R30, R39, R48, R57, R66, R75, R84, R93, R102, R111, R120, R129, R138: 220K; 0402-TIGHT
U1, U3, U7, U10, U13, U16, U19, U22, U25, U28, U31, U34, U37, U40, U43, U46: ARTEMIS_MODULESMD; ARTEMIS_FP
U2, U5, U9, U12, U15, U18, U21, U24, U27, U30, U33, U36, U39, U42, U45, U48: TSV524; QFN-16
U4, U6, U8, U11, U14, U17, U20, U23, U26, U29, U32, U35, U38, U41, U44, U47: CH340E_MSOP10; MSOP10
U$1, U$2, U$4, U$7, U$13, U$15, U$19, U$21, U$25, U$27, U$31, U$33, U$37, U$39, U$43, U$45, U$49, U$51, U$55, U$57, U$61, U$63, U$67, U$69, U$73, U$75, U$79, U$81, U$85, U$87, U$91, U$93: MICROMOD_MI_LOGO_.35
U$3, U$5, U$14, U$20, U$26, U$32, U$38, U$44, U$50, U$56, U$62, U$68, U$74, U$80, U$86, U$92: MICROMOD_LOGO_.35
U$6, U$8, U$16, U$22, U$28, U$34, U$40, U$46, U$52, U$58, U$64, U$70, U$76, U$82, U$88, U$94: MICROMOD_ARTEMIS0
U$9, U$10, U$17, U$23, U$29, U$35, U$41, U$47, U$53, U$59, U$65, U$71, U$77, U$83, U$89, U$95: ARTEMIS0
U$11, U$12, U$18, U$24, U$30, U$36, U$42, U$48, U$54, U$60, U$66, U$72, U$78, U$84, U$90, U$96: STAT0
Y1, Y2, Y3, Y4, Y5, Y6, Y7, Y8, Y9, Y10, Y11, Y12, Y13, Y14, Y15, Y16: 32.768kHz; CRYSTAL-SMD-3.2X1.5MM

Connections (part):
3.3V: C2.1, C17.1, C18.1, D7.A, J1.2, J1.74, U6.7, U6.10
3.3V1: C7.1, C8.1, C15.1, D3.A, J2.2, J2.74, U4.7, U4.10
3.3V2: C24.1, C25.1, C31.1, D5.A, J3.2, J3.74, U8.7, U8.10
3.3V3: C36.1, C37.1, C42.1, D8.A, J4.2, J4.74, U11.7, U11.10
3.3V4: C47.1, C48.1, C53.1, D10.A, J5.2, J5.74, U14.7, U14.10
3.3V5: C58.1, C59.1, C64.1, D12.A, J6.2, J6.74, U17.7, U17.10
3.3V6: C69.1, C70.1, C75.1, D14.A, J7.2, J7.74, U20.7, U20.10
3.3V7: C80.1, C81.1, C86.1, D16.A, J8.2, J8.74, U23.7, U23.10
3.3V8: C91.1, C92.1, C97.1, D18.A, J9.2, J9.74, U26.7, U26.10
3.3V9: C102.1, C103.1, C108.1, D20.A, J10.2, J10.74, U29.7, U29.10
3.3V10: C113.1, C114.1, C119.1, D22.A, J11.2, J11.74, U32.7, U32.10
3.3V11: C124.1, C125.1, C130.1, D24.A, J12.2, J12.74, U35.7, U35.10
3.3V12: C135.1, C136.1, C141.1, D26.A, J13.2, J13.74, U38.7, U38.10
3.3V13: C146.1, C147.1, C152.1, D28.A, J14.2, J14.74, U41.7, U41.10
3.3V14: C157.1, C158.1, C163.1, D30.A, J15.2, J15.74, U44.7, U44.10
3.3V15: C168.1, C169.1, C174.1, D32.A, J16.2, J16.74, U47.7, U47.10
3.3V_EN: J1.4, U1.D3
3.3V_EN1: J2.4, U3.D3
3.3V_EN2: J3.4, U7.D3
3.3V_EN3: J4.4, U10.D3
3.3V_EN4: J5.4, U13.D3
3.3V_EN5: J6.4, U16.D3
3.3V_EN6: J7.4, U19.D3
3.3V_EN7: J8.4, U22.D3
3.3V_EN8: J9.4, U25.D3
3.3V_EN9: J10.4, U28.D3
3.3V_EN10: J11.4, U31.D3
3.3V_EN11: J12.4, U34.D3
3.3V_EN12: J13.4, U37.D3
3.3V_EN13: J14.4, U40.D3
3.3V_EN14: J15.4, U43.D3
3.3V_EN15: J16.4, U46.D3
!RESET!: C20.2, C28.1, J1.6, R14.1, U1.~RST
!RESET!1: C9.2, C12.1, J2.6, R9.1, U3.~RST
!RESET!2: C26.2, C29.1, J3.6, R20.1, U7.~RST
!RESET!3: C38.2, C40.1, J4.6, R29.1, U10.~RST
!RESET!4: C49.2, C51.1, J5.6, R38.1, U13.~RST
!RESET!5: C60.2, C62.1, J6.6, R47.1, U16.~RST
!RESET!6: C71.2, C73.1, J7.6, R56.1, U19.~RST
!RESET!7: C82.2, C84.1, J8.6, R65.1, U22.~RST
!RESET!8: C93.2, C95.1, J9.6, R74.1, U25.~RST
!RESET!9: C104.2, C106.1, J10.6, R83.1, U28.~RST
!RESET!10: C115.2, C117.1, J11.6, R92.1, U31.~RST
!RESET!11: C126.2, C128.1, J12.6, R101.1, U34.~RST
!RESET!12: C137.2, C139.1, J13.6, R110.1, U37.~RST
!RESET!13: C148.2, C150.1, J14.6, R119.1, U40.~RST
!RESET!14: C159.2, C161.1, J15.6, R128.1, U43.~RST
!RESET!15: C170.2, C172.1, J16.6, R137.1, U46.~RST
!RTS: C20.1, C21.1, U6.4
!RTS1: C9.1, C10.1, U4.4
!RTS2: C26.1, C27.1, U8.4
!RTS3: C38.1, C39.1, U11.4
!RTS4: C49.1, C50.1, U14.4
!RTS5: C60.1, C61.1, U17.4
!RTS6: C71.1, C72.1, U20.4
!RTS7: C82.1, C83.1, U23.4
!RTS8: C93.1, C94.1, U26.4
!RTS9: C104.1, C105.1, U29.4
!RTS10: C115.1, C116.1, U32.4
!RTS11: C126.1, C127.1, U35.4
!RTS12: C137.1, C138.1, U38.4
!RTS13: C148.1, C149.1, U41.4
!RTS14: C159.1, C160.1, U44.4
!RTS15: C170.1, C171.1, U47.4
ADC0: J1.34, U2.1
ADC0_BUFF1: R3.2, U2.15, U2.16
ADC0_BUFF2: R3.1, R5.2, U2.4
ADC0_BUFF3: R13.1, R16.2, U5.4
ADC0_BUFF4: R13.2, U5.15, U5.16
ADC0_BUFF5: R24.1, R25.2, U9.4
ADC0_BUFF6: R24.2, U9.15, U9.16
ADC0_BUFF7: R33.1, R34.2, U12.4
ADC0_BUFF8: R33.2, U12.15, U12.16
ADC0_BUFF9: R42.1, R43.2, U15.4
ADC0_BUFF10: R42.2, U15.15, U15.16
ADC0_BUFF11: R51.1, R52.2, U18.4
ADC0_BUFF12: R51.2, U18.15, U18.16
ADC0_BUFF13: R60.1, R61.2, U21.4
ADC0_BUFF14: R60.2, U21.15, U21.16
ADC0_BUFF15: R69.1, R70.2, U24.4
ADC0_BUFF16: R69.2, U24.15, U24.16
ADC0_BUFF17: R78.1, R79.2, U27.4
ADC0_BUFF18: R78.2, U27.15, U27.16
ADC0_BUFF19: R87.1, R88.2, U30.4
ADC0_BUFF20: R87.2, U30.15, U30.16
ADC0_BUFF21: R96.1, R97.2, U33.4
ADC0_BUFF22: R96.2, U33.15, U33.16
ADC0_BUFF23: R105.1, R106.2, U36.4
ADC0_BUFF24: R105.2, U36.15, U36.16
ADC0_BUFF25: R114.1, R115.2, U39.4
ADC0_BUFF26: R114.2, U39.15, U39.16
ADC0_BUFF27: R123.1, R124.2, U42.4
ADC0_BUFF28: R123.2, U42.15, U42.16
ADC0_BUFF29: R132.1, R133.2, U45.4
ADC0_BUFF30: R132.2, U45.15, U45.16
ADC0_BUFF31: R141.1, R142.2, U48.4
ADC0_BUFF32: R141.2, U48.15, U48.16
ADC1: J1.38, U2.12
ADC1_BUFF1: R17.1, R18.2, U5.9
ADC1_BUFF2: R6.1, R7.2, U2.9
ADC1_BUFF3: R26.1, R27.2, U9.9
ADC1_BUFF4: R35.1, R36.2, U12.9
ADC1_BUFF5: R44.1, R45.2, U15.9
ADC1_BUFF6: R53.1, R54.2, U18.9
ADC1_BUFF7: R62.1, R63.2, U21.9
ADC1_BUFF8: R71.1, R72.2, U24.9
ADC1_BUFF9: R80.1, R81.2, U27.9
ADC1_BUFF10: R89.1, R90.2, U30.9
ADC1_BUFF11: R98.1, R99.2, U33.9
ADC1_BUFF12: R107.1, R108.2, U36.9
ADC1_BUFF13: R116.1, R117.2, U39.9
ADC1_BUFF14: R125.1, R126.2, U42.9
ADC1_BUFF15: R134.1, R135.2, U45.9
ADC1_BUFF16: R143.1, R144.2, U48.9
ADC2: J2.34, U5.1
ADC3: J2.38, U5.12
ADC4: J3.34, U9.1
ADC5: J3.38, U9.12
ADC6: J4.34, U12.1
ADC7: J4.38, U12.12
ADC8: J5.34, U15.1
ADC9: J5.38, U15.12
ADC10: J6.34, U18.1
ADC11: J6.38, U18.12
ADC12: J7.34, U21.1
ADC13: J7.38, U21.12
ADC14: J8.34, U24.1
ADC15: J8.38, U24.12
ADC16: J9.34, U27.1
ADC17: J9.38, U27.12
ADC18: J10.34, U30.1
ADC19: J10.38, U30.12
ADC20: J11.34, U33.1
ADC21: J11.38, U33.12
ADC22: J12.34, U36.1
ADC23: J12.38, U36.12
ADC24: J13.34, U39.1
ADC25: J13.38, U39.12
ADC26: J14.34, U42.1
ADC27: J14.38, U42.12
ADC28: J15.34, U45.1
ADC29: J15.38, U45.12
ADC30: J16.34, U48.1
ADC31: J16.38, U48.12
ADC_BUFF1: R6.2, U2.13, U2.14
ADC_BUFF2: R17.2, U5.13, U5.14
ADC_BUFF3: R26.2, U9.13, U9.14
ADC_BUFF4: R35.2, U12.13, U12.14
ADC_BUFF5: R44.2, U15.13, U15.14
ADC_BUFF6: R53.2, U18.13, U18.14
ADC_BUFF7: R62.2, U21.13, U21.14
ADC_BUFF8: R71.2, U24.13, U24.14
ADC_BUFF9: R80.2, U27.13, U27.14
ADC_BUFF10: R89.2, U30.13, U30.14
ADC_BUFF11: R98.2, U33.13, U33.14
ADC_BUFF12: R107.2, U36.13, U36.14
ADC_BUFF13: R116.2, U39.13, U39.14
ADC_BUFF14: R125.2, U42.13, U42.14
ADC_BUFF15: R134.2, U45.13, U45.14
ADC_BUFF16: R143.2, U48.13, U48.14
ADC_D+: J1.63, U1.~AD13
ADC_D+1: J2.63, U3.~AD13
ADC_D+2: J3.63, U7.~AD13
ADC_D+3: J4.63, U10.~AD13
ADC_D+4: J5.63, U13.~AD13
ADC_D+5: J6.63, U16.~AD13
ADC_D+6: J7.63, U19.~AD13
ADC_D+7: J8.63, U22.~AD13
ADC_D+8: J9.63, U25.~AD13
ADC_D+9: J10.63, U28.~AD13
ADC_D+10: J11.63, U31.~AD13
ADC_D+11: J12.63, U34.~AD13
ADC_D+12: J13.63, U37.~AD13
ADC_D+13: J14.63, U40.~AD13
ADC_D+14: J15.63, U43.~AD13
ADC_D+15: J16.63, U46.~AD13
BATT_VIN/1: J2.49, R11.2
BATT_VIN/2: J3.49, R22.2
BATT_VIN/3: J1.49, R2.2
BATT_VIN/4: J4.49, R31.2
BATT_VIN/5: J5.49, R40.2
BATT_VIN/6: J6.49, R49.2
BATT_VIN/7: J7.49, R58.2
BATT_VIN/8: J8.49, R67.2
BATT_VIN/9: J9.49, R76.2
BATT_VIN/10: J10.49, R85.2
BATT_VIN/11: J11.49, R94.2
BATT_VIN/12: J12.49, R103.2
BATT_VIN/13: J13.49, R112.2
BATT_VIN/14: J14.49, R121.2
BATT_VIN/15: J15.49, R130.2
BATT_VIN/16: J16.49, R139.2
BOOT: C21.2, J1.11, R15.2, U1.BOOT
BOOT1: C10.2, J2.11, R10.2, U3.BOOT
BOOT2: C27.2, J3.11, R21.2, U7.BOOT
BOOT3: C39.2, J4.11, R30.2, U10.BOOT
BOOT4: C50.2, J5.11, R39.2, U13.BOOT
BOOT5: C61.2, J6.11, R48.2, U16.BOOT
BOOT6: C72.2, J7.11, R57.2, U19.BOOT
BOOT7: C83.2, J8.11, R66.2, U22.BOOT
BOOT8: C94.2, J9.11, R75.2, U25.BOOT
BOOT9: C105.2, J10.11, R84.2, U28.BOOT
BOOT10: C116.2, J11.11, R93.2, U31.BOOT
BOOT11: C127.2, J12.11, R102.2, U34.BOOT
BOOT12: C138.2, J13.11, R111.2, U37.BOOT
BOOT13: C149.2, J14.11, R120.2, U40.BOOT
BOOT14: C160.2, J15.11, R129.2, U43.BOOT
BOOT15: C171.2, J16.11, R138.2, U46.BOOT
CAM_MCLK: J1.56, J1.58, U1.~D18
CAM_MCLK1: J2.56, J2.58, U3.~D18
CAM_MCLK2: J3.56, J3.58, U7.~D18
CAM_MCLK3: J4.56, J4.58, U10.~D18
CAM_MCLK4: J5.56, J5.58, U13.~D18
CAM_MCLK5: J6.56, J6.58, U16.~D18
CAM_MCLK6: J7.56, J7.58, U19.~D18
CAM_MCLK7: J8.56, J8.58, U22.~D18
CAM_MCLK8: J9.56, J9.58, U25.~D18
CAM_MCLK9: J10.56, J10.58, U28.~D18
CAM_MCLK10: J11.56, J11.58, U31.~D18
CAM_MCLK11: J12.56, J12.58, U34.~D18
CAM_MCLK12: J13.56, J13.58, U37.~D18
CAM_MCLK13: J14.56, J14.58, U40.~D18
CAM_MCLK14: J15.56, J15.58, U43.~D18
CAM_MCLK15: J16.56, J16.58, U46.~D18
CAM_PCLK: J1.54, U1.~AD11
CAM_PCLK1: J2.54, U3.~AD11
CAM_PCLK2: J3.54, U7.~AD11
CAM_PCLK3: J4.54, U10.~AD11
CAM_PCLK4: J5.54, U13.~AD11
CAM_PCLK5: J6.54, U16.~AD11
CAM_PCLK6: J7.54, U19.~AD11
CAM_PCLK7: J8.54, U22.~AD11
CAM_PCLK8: J9.54, U25.~AD11
CAM_PCLK9: J10.54, U28.~AD11
CAM_PCLK10: J11.54, U31.~AD11
CAM_PCLK11: J12.54, U34.~AD11
CAM_PCLK12: J13.54, U37.~AD11
CAM_PCLK13: J14.54, U40.~AD11
CAM_PCLK14: J15.54, U43.~AD11
CAM_PCLK15: J16.54, U46.~AD11
CTS1: J1.15, U1.D17
CTS2: J2.15, U3.D17
CTS3: J3.15, U7.D17
CTS4: J4.15, U10.D17
CTS5: J5.15, U13.D17
CTS6: J6.15, U16.D17
CTS7: J7.15, U19.D17
CTS8: J8.15, U22.D17
CTS9: J9.15, U25.D17
CTS10: J10.15, U28.D17
CTS11: J11.15, U31.D17
CTS12: J12.15, U34.D17
CTS13: J13.15, U37.D17
CTS14: J14.15, U40.D17
CTS15: J15.15, U43.D17
CTS16: J16.15, U46.D17
D0: J1.10, U1.D0
D1: J1.18, U1.D1
D2: J2.10, U3.D0
D3: J2.18, U3.D1
D4: J3.10, U7.D0
D5: J3.18, U7.D1
D6: J4.10, U10.D0
D7: J4.18, U10.D1
D8: J5.10, U13.D0
D9: J5.18, U13.D1
D10: J6.10, U16.D0
D11: J6.18, U16.D1
D12: J7.10, U19.D0
D13: J7.18, U19.D1
D14: J8.10, U22.D0
D15: J8.18, U22.D1
D16: J9.10, U25.D0
D17: J9.18, U25.D1
D18: J10.10, U28.D0
D19: J10.18, U28.D1
D20: J11.10, U31.D0
D21: J11.18, U31.D1
D22: J12.10, U34.D0
D23: J12.18, U34.D1
D24: J13.10, U37.D0
D25: J13.18, U37.D1
D26: J14.10, U40.D0
D27: J14.18, U40.D1
D28: J15.10, U43.D0
D29: J15.18, U43.D1
D30: J16.10, U46.D0
D31: J16.18, U46.D1
GND: C1.2, C2.2, C3.2, C4.2, C11.1, C13.1, C17.2, C18.2, C28.2, D2.C, J1.1, J1.7, J1.33, J1.36, J1.39, J1.45, J1.75, J1.GND1, J1.GND2, J1.GND3, R4.1, R5.1, R7.1, R15.1, U1.GND@1, U1.GND@22, U1.GND@38, U1.GND@39, U1.GND@47, U1.GND@59, U2.11, U6.3
GND1: C5.1, C6.1, C7.2, C8.2, C12.2, C14.2, C15.2, C16.2, C19.2, D1.C, J2.1, J2.7, J2.33, J2.36, J2.39, J2.45, J2.75, J2.GND1, J2.GND2, J2.GND3, R10.1, R12.1, R16.1, R18.1, U3.GND@1, U3.GND@22, U3.GND@38, U3.GND@39, U3.GND@47, U3.GND@59, U4.3, U5.11
GND2: C22.1, C23.1, C24.2, C25.2, C29.2, C30.2, C31.2, C32.2, C33.2, D4.C, J3.1, J3.7, J3.33, J3.36, J3.39, J3.45, J3.75, J3.GND1, J3.GND2, J3.GND3, R21.1, R23.1, R25.1, R27.1, U7.GND@1, U7.GND@22, U7.GND@38, U7.GND@39, U7.GND@47, U7.GND@59, U8.3, U9.11
GND3: C34.1, C35.1, C36.2, C37.2, C40.2, C41.2, C42.2, C43.2, C44.2, D6.C, J4.1, J4.7, J4.33, J4.36, J4.39, J4.45, J4.75, J4.GND1, J4.GND2, J4.GND3, R30.1, R32.1, R34.1, R36.1, U10.GND@1, U10.GND@22, U10.GND@38, U10.GND@39, U10.GND@47, U10.GND@59, U11.3, U12.11
GND4: C45.1, C46.1, C47.2, C48.2, C51.2, C52.2, C53.2, C54.2, C55.2, D9.C, J5.1, J5.7, J5.33, J5.36, J5.39, J5.45, J5.75, J5.GND1, J5.GND2, J5.GND3, R39.1, R41.1, R43.1, R45.1, U13.GND@1, U13.GND@22, U13.GND@38, U13.GND@39, U13.GND@47, U13.GND@59, U14.3, U15.11
GND5: C56.1, C57.1, C58.2, C59.2, C62.2, C63.2, C64.2, C65.2, C66.2, D11.C, J6.1, J6.7, J6.33, J6.36, J6.39, J6.45, J6.75, J6.GND1, J6.GND2, J6.GND3, R48.1, R50.1, R52.1, R54.1, U16.GND@1, U16.GND@22, U16.GND@38, U16.GND@39, U16.GND@47, U16.GND@59, U17.3, U18.11
GND6: C67.1, C68.1, C69.2, C70.2, C73.2, C74.2, C75.2, C76.2, C77.2, D13.C, J7.1, J7.7, J7.33, J7.36, J7.39, J7.45, J7.75, J7.GND1, J7.GND2, J7.GND3, R57.1, R59.1, R61.1, R63.1, U19.GND@1, U19.GND@22, U19.GND@38, U19.GND@39, U19.GND@47, U19.GND@59, U20.3, U21.11
GND7: C78.1, C79.1, C80.2, C81.2, C84.2, C85.2, C86.2, C87.2, C88.2, D15.C, J8.1, J8.7, J8.33, J8.36, J8.39, J8.45, J8.75, J8.GND1, J8.GND2, J8.GND3, R66.1, R68.1, R70.1, R72.1, U22.GND@1, U22.GND@22, U22.GND@38, U22.GND@39, U22.GND@47, U22.GND@59, U23.3, U24.11
GND8: C89.1, C90.1, C91.2, C92.2, C95.2, C96.2, C97.2, C98.2, C99.2, D17.C, J9.1, J9.7, J9.33, J9.36, J9.39, J9.45, J9.75, J9.GND1, J9.GND2, J9.GND3, R75.1, R77.1, R79.1, R81.1, U25.GND@1, U25.GND@22, U25.GND@38, U25.GND@39, U25.GND@47, U25.GND@59, U26.3, U27.11
GND9: C100.1, C101.1, C102.2, C103.2, C106.2, C107.2, C108.2, C109.2, C110.2, D19.C, J10.1, J10.7, J10.33, J10.36, J10.39, J10.45, J10.75, J10.GND1, J10.GND2, J10.GND3, R84.1, R86.1, R88.1, R90.1, U28.GND@1, U28.GND@22, U28.GND@38, U28.GND@39, U28.GND@47, U28.GND@59, U29.3, U30.11
GND10: C111.1, C112.1, C113.2, C114.2, C117.2, C118.2, C119.2, C120.2, C121.2, D21.C, J11.1, J11.7, J11.33, J11.36, J11.39, J11.45, J11.75, J11.GND1, J11.GND2, J11.GND3, R93.1, R95.1, R97.1, R99.1, U31.GND@1, U31.GND@22, U31.GND@38, U31.GND@39, U31.GND@47, U31.GND@59, U32.3, U33.11
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

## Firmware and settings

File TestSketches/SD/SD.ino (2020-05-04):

/*
  SD card test

  This example shows how use the utility libraries on which the'
  SD library is based in order to get info about your SD card.
  Very useful for testing a card when you're not sure whether its working or not.

  The circuit:
    SD card attached to SPI bus as follows:
 ** MOSI - pin 11 on Arduino Uno/Duemilanove/Diecimila
 ** MISO - pin 12 on Arduino Uno/Duemilanove/Diecimila
 ** CLK - pin 13 on Arduino Uno/Duemilanove/Diecimila
 ** CS - depends on your SD card shield or module.
 		Pin 4 used here for consistency with other Arduino examples


  created  28 Mar 2011
  by Limor Fried
  modified 9 Apr 2012
  by Tom Igoe
*/
// include the SD library:
#include <SPI.h>
#include <SD.h>

// set up variables using the SD utility library functions:
Sd2Card card;
SdVolume volume;
SdFile root;

//On MM Carrier boards the SD socket is tied to the SDIO bus. This bus
//can be started in SPI mode or in the advanced SDIO mode. For SPI
//the CS pin is DATA3 or 23 on Artemis.
const int chipSelect = 23;

void setup() {
  // Open serial communications and wait for port to open:
  Serial.begin(115200);
  while (!Serial) {
    ; // wait for serial port to connect. Needed for native USB port only
  }


  Serial.print("\nInitializing SD card...");

  // we'll use the initialization code from the utility libraries
  // since we're just testing if the card is working!
  if (!card.init(SPI_HALF_SPEED, chipSelect)) {
    Serial.println("initialization failed. Things to check:");
    Serial.println("* is a card inserted?");
    Serial.println("* is your wiring correct?");
    Serial.println("* did you change the chipSelect pin to match your shield or module?");
    while (1);
  } else {
    Serial.println("Wiring is correct and a card is present.");
  }

  // print the type of card
  Serial.println();
  Serial.print("Card type:         ");
  switch (card.type()) {
    case SD_CARD_TYPE_SD1:
      Serial.println("SD1");
      break;
    case SD_CARD_TYPE_SD2:
      Serial.println("SD2");
      break;
    case SD_CARD_TYPE_SDHC:
      Serial.println("SDHC");
      break;
    default:
      Serial.println("Unknown");
  }

  // Now we will try to open the 'volume'/'partition' - it should be FAT16 or FAT32
  if (!volume.init(card)) {
    Serial.println("Could not find FAT16/FAT32 partition.\nMake sure you've formatted the card");
    while (1);
  }

  Serial.print("Clusters:          ");
  Serial.println(volume.clusterCount());
  Serial.print("Blocks x Cluster:  ");
  Serial.println(volume.blocksPerCluster());

  Serial.print("Total Blocks:      ");
  Serial.println(volume.blocksPerCluster() * volume.clusterCount());
  Serial.println();

  // print the type and size of the first FAT-type volume
  uint32_t volumesize;
  Serial.print("Volume type is:    FAT");
  Serial.println(volume.fatType(), DEC);

  volumesize = volume.blocksPerCluster();    // clusters are collections of blocks
  volumesize *= volume.clusterCount();       // we'll have a lot of clusters
  volumesize /= 2;                           // SD card blocks are always 512 bytes (2 blocks are 1KB)
  Serial.print("Volume size (Kb):  ");
  Serial.println(volumesize);
  Serial.print("Volume size (Mb):  ");
  volumesize /= 1024;
  Serial.println(volumesize);
  Serial.print("Volume size (Gb):  ");
  Serial.println((float)volumesize / 1024.0);

  Serial.println("\nFiles found on the card (name, date and size in bytes): ");
  root.openRoot(volume);

  // list all files in the card with date and size
  root.ls(LS_R | LS_DATE | LS_SIZE);
}

void loop(void) {
}

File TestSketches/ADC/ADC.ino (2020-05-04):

/*

*/

#define ANALOG_RESOLUTION pow(2, 14);

void setup()
{
  Serial.begin(115200);
  Serial.println("Read example");

  pinMode(LED_BUILTIN, OUTPUT);

  analogReadResolution(14); //Set resolution to 14 bit
}

void loop()
{
  digitalWrite(LED_BUILTIN, LOW);

  int myAnalog0 = analogRead(A0);
  float myVoltage0 = myAnalog0 * 3.3 / ANALOG_RESOLUTION;
  Serial.print("A0 voltage: ");
  Serial.print(myVoltage0, 3);

  int myAnalog1 = analogRead(A1);
  float myVoltage1 = myAnalog1 * 3.3 / ANALOG_RESOLUTION;
  Serial.print("\tA1 voltage: ");
  Serial.print(myVoltage1, 3);

  int battvin = analogRead(BATTVIN3);
  Serial.print("\tbattvin: ");
  Serial.print(battvin);
  float battVoltage = battvin * 3.3 / ANALOG_RESOLUTION;
  Serial.print("\tBatt voltage: ");
  Serial.print(battVoltage, 3);

  //Serial.print("\tinternalTemp: ");
  //Serial.print(getTemperature(), 2);

  Serial.println();

  digitalWrite(LED_BUILTIN, HIGH);
  delay(50);
}

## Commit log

2020-03-24 Production of v10
    [Artemis-MicroMod-Panel.GBL, Artemis-MicroMod-Panel.GBO, Artemis-MicroMod-Panel.GBP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]
2020-04-08 Adding panel files for v10
    [Artemis-MicroMod-Panel.GBL, Artemis-MicroMod-Panel.GBO, Artemis-MicroMod-Panel.GBP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]
2020-04-08 v11 adds ADC buffers, 3.3V enable, RTC backup power, 0402 components.
    [Artemis-MicroMod.brd]
2020-04-15 Routed CAM_PCLK
    [Artemis-MicroMod-Panel.brd, Artemis-MicroMod.brd, Artemis-MicroMod.sch]
2020-04-15 Double buffered ADC.
    [Artemis-MicroMod.brd, Artemis-MicroMod.sch]
2020-04-15 Add v1.1 production files
    [Artemis-MicroMod-Panel.GBL, Artemis-MicroMod-Panel.GBO, Artemis-MicroMod-Panel.GBP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]
2020-05-04 Add reverse diode to prevent RTC 3.3V from driving 3.3V bus. Add test sketches.
    [Artemis-MicroMod-Panel.brd, Artemis-MicroMod.brd, Artemis-MicroMod.sch]
2020-05-08 Add MicroMod logo, double route MCLK.
    [Artemis-MicroMod.brd, Artemis-MicroMod.sch]
2020-05-08 Add MicroMod logo.
    [Artemis-MicroMod.brd]
2020-05-13 Route from opamp for better AOI. fix DRC error. Add v1.2 panel files.
    [Artemis-MicroMod-Panel.GBL, Artemis-MicroMod-Panel.GBO, Artemis-MicroMod-Panel.GBP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]
2020-05-20 File rename
    [Artemis-MicroMod-Panel.GBL, Artemis-MicroMod-Panel.GBO, Artemis-MicroMod-Panel.GBP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]
2020-06-08 Add missing net to Xtal
    [MicroMod-Artemis-ProcessorBoard.brd, MicroMod-Artemis-ProcessorBoard.sch]
2020-06-08 Adding v13 production files
    [MicroMod-Artemis-ProcessorBoard-Panel.GBL, MicroMod-Artemis-ProcessorBoard-Panel.GBO, MicroMod-Artemis-ProcessorBoard-Panel.GBP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]
2020-06-18 Fix SDA1/SCL1, CS1, and VIN/3 incorrect pin locations.
    [MicroMod-Artemis-ProcessorBoard.brd, MicroMod-Artemis-ProcessorBoard.sch]
2020-06-18 Roll version to v1.4
    [MicroMod-Artemis-ProcessorBoard.brd, MicroMod-Artemis-ProcessorBoard.sch]
2020-06-23 Connect SPI pins to support Quad SPI. Move TX1 to AD12
    [MicroMod-Artemis-ProcessorBoard.brd, MicroMod-Artemis-ProcessorBoard.sch]
2020-08-13 Adding additional decoupling, change version to v16.
    [MicroMod-Artemis-ProcessorBoard-Panel.brd, MicroMod-Artemis-ProcessorBoard.brd, MicroMod-Artemis-ProcessorBoard.sch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]
2020-10-01 Update SPI port 0/1 net names.
    [MicroMod-Artemis-ProcessorBoard.brd, MicroMod-Artemis-ProcessorBoard.sch]
2020-10-02 Change 3.3V back feed diode to lower v-drop.
    [MicroMod-Artemis-ProcessorBoard.brd, MicroMod-Artemis-ProcessorBoard.sch]
2020-10-03 Move CH340 to 3.3V side of diode. Replace D7 with 0.3uA leakage diode.
    [MicroMod-Artemis-ProcessorBoard.brd, MicroMod-Artemis-ProcessorBoard.sch]
2020-10-05 Adding v17 production files
    [MicroMod-Artemis-ProcessorBoard-Panel.brd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]

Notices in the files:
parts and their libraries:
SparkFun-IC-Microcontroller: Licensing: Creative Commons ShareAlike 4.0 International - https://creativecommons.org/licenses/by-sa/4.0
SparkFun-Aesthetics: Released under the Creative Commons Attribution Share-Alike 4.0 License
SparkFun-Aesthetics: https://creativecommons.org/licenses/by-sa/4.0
